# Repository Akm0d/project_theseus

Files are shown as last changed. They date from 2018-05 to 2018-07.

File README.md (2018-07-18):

# Project Theseus
This project is forked from the private repo of the OpenWest Defusal Station project. It is named "Project Theseus" after the paradox of the Ship of Theseus; a thought experiment that raises the question of whether an object that has had all of its components replaced remains fundamentally the same object.

# Contribution Guidelines
1. Create a branch for your code and merge it to master once the changes are stable
2. Keep the file structure as organized as possible
3. Never commit binaries, hidden files created by your IDE, or Windows-style line endings.
4. Keep detailed comments of what each function is meant to do
5. Follow the PEP-8 standard when writing python https://www.python.org/dev/peps/pep-0008/
6. Use comments starting with TODO to mark a feature that needs to be implemented and FIXME to mark features that need to be improved
7. If you are stuck, then it is absolutely OK to ask for help

# Getting Started
```bash
$ sudo apt-get update
$ sudo apt-get install python3 git python3-pip
$ git clone https://github.com/jtylers/project_theseus.git
$ cd project_theseus
$ git submodule update --init
$ pip3 install -r requirements.txt
$ ./serve.py
$ firefox 127.0.0.1:5000
```
I highly suggest using PyCharm if you are working with Flask and Python
```bash
$ sudo apt-get update
$ sudo apt-get install snapd
$ snap install pycharm-community
```
Add the project root to your python path for things to run correctly
```bash
$ echo "export PYTHONPATH=$PYTHONPATH:$HOME/project_theseus" >> ~/.profile
$ source ~/.profile
```

## Raspberry pi - ARCH Linux Setup
```bash
$ ## login with user: root password: root
$ # Delete default user
$ userdel alarm
$ # Create a new adminuser
$ useradd admin
$ # Set password for admin
$ passwd admin
$ # Make a home folder for admin
$ mkdir -p /home/admin
$ # Change ownership of the admin's home folder
$ chown -R admin:admin /home/admin
$ pacman -S sudo
$ # Grant admin sudo privileges
$ visudo
$ ## Press SHIFT + G then SHIFT + A
$ ## type "admin ALL=(ALL) ALL" without the quotes
$ ## save and quit by pressing ESCAPE, typing ":x" and pressing ENTER
$ # Remove root's password entry so that you can only log in as "admin" and use sudo and to do root stuff
$ vim /etc/shadow
$ ## replace root's password hash with !
$ # Install dependencies
$ pacman -S fakeroot gcc git i2c-tools make nginx packer python python-dateutil python-flask python-flask-restful python-pip tmux vim 
$ packer -S raspi-config
$ # Enable I2C 
$ echo "dtparam=i2c_arm=on"| sudo tee -a /boot/config.txt
$ sudo reboot
$ ## Log in as admin
$ ## Allow admin to access i2c
$ sudo chown admin:admin /dev/i2c*
$ ## Proceed with the instructions from the "Getting Started" section
$ ## Run project_theseus/pi_setup.sh
```

## Where are variables stored?
Stored in the database
```
ID
Name
Laser   -- Deprecated
Code
Color
Time    -- Stored as a datetime object but written at end of game
Success
```

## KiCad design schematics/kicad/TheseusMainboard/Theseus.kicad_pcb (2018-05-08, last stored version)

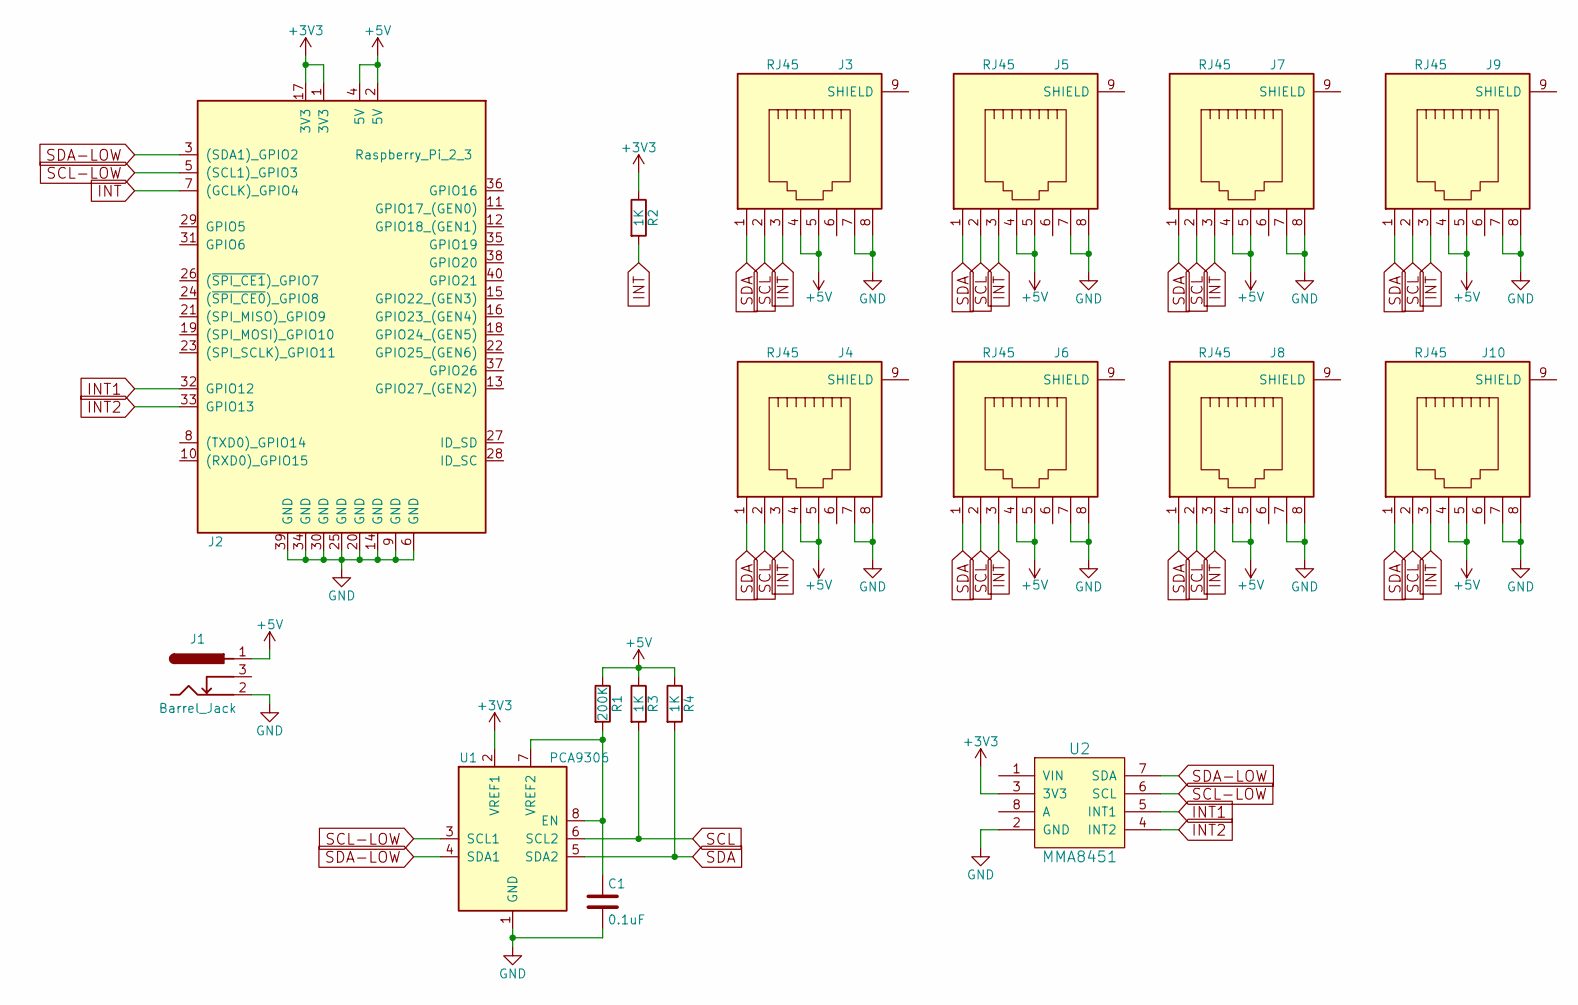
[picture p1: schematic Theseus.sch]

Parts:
C1: 0.1uF; C_0805_HandSoldering
J1: Barrel_Jack; POWER_JACK_PTH
J2: Raspberry_Pi_2_3; Pin_Header_Straight_2x20
J3, J4, J5, J6, J7, J8, J9, J10: RJ45; RJ45-8
R1: 200K; R_0805_HandSoldering
R2, R3, R4: 1K; R_0805_HandSoldering
U1: PCA9306; SO08
U2: MMA8451; Pin_Header_Straight_1x08_Pitch2.54mm

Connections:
+3V3: J2.1 (3V3), J2.17 (3V3), R2.1, U1.2 (VREF1), U2.3 (3V3)
+5V: J1.1, J2.2 (5V), J2.4 (5V), J3.4, J3.5, J4.4, J4.5, J5.4, J5.5, J6.4, J6.5, J7.4, J7.5, J8.4, J8.5, J9.4, J9.5, J10.4, J10.5, R1.1, R3.1, R4.1
GND: C1.2, J1.2, J2.6 (GND), J2.9 (GND), J2.14 (GND), J2.20 (GND), J2.25 (GND), J2.30 (GND), J2.34 (GND), J2.39 (GND), J3.7, J3.8, J4.7, J4.8, J5.7, J5.8, J6.7, J6.8, J7.7, J7.8, J8.7, J8.8, J9.7, J9.8, J10.7, J10.8, U1.1 (GND), U2.2 (GND)
INT: J2.7 ((GCLK)_GPIO4), J3.3, J4.3, J5.3, J6.3, J7.3, J8.3, J9.3, J10.3, R2.2
INT1: J2.32 (GPIO12), U2.5 (INT1)
INT2: J2.33 (GPIO13), U2.4 (INT2)
unnamed: C1.1, R1.2, U1.7 (VREF2), U1.8 (EN)
SCL: J3.2, J4.2, J5.2, J6.2, J7.2, J8.2, J9.2, J10.2, R3.2, U1.6 (SCL2)
SCL-LOW: J2.5 ((SCL1)_GPIO3), U1.3 (SCL1), U2.6 (SCL)
SDA: J3.1, J4.1, J5.1, J6.1, J7.1, J8.1, J9.1, J10.1, R4.2, U1.5 (SDA2)
SDA-LOW: J2.3 ((SDA1)_GPIO2), U1.4 (SDA1), U2.7 (SDA)

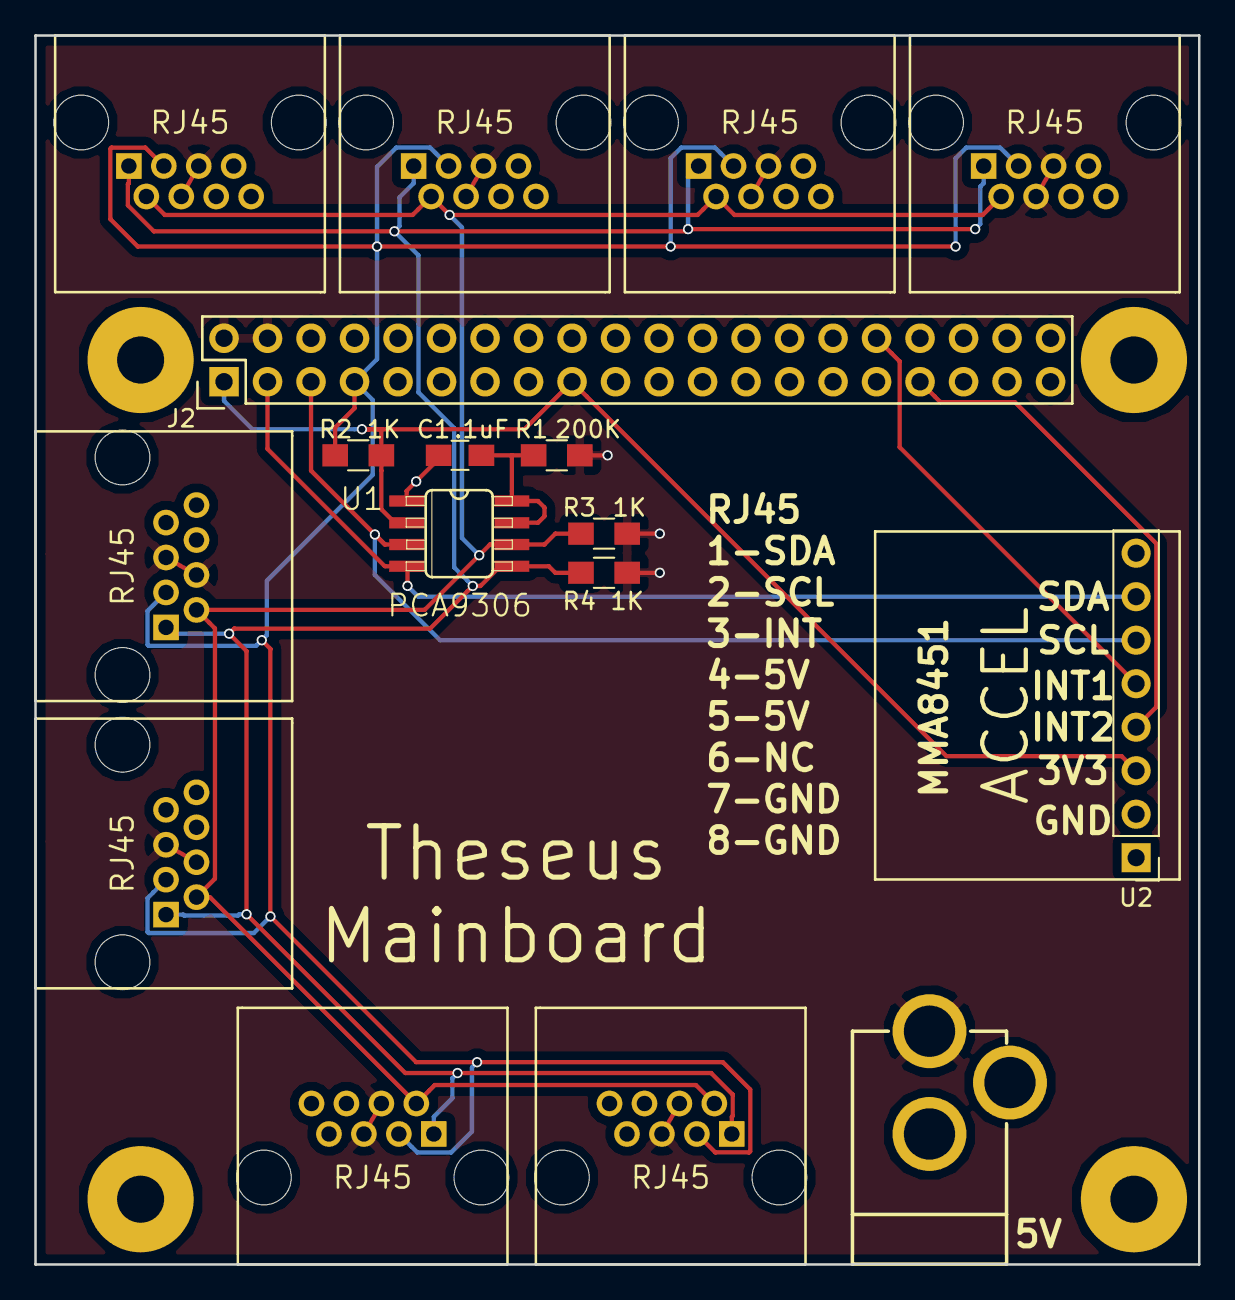
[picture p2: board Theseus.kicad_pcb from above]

Board: 2 copper layers, 67.9 x 71.8 mm, 17 parts (0 on the bottom side), 11 nets.

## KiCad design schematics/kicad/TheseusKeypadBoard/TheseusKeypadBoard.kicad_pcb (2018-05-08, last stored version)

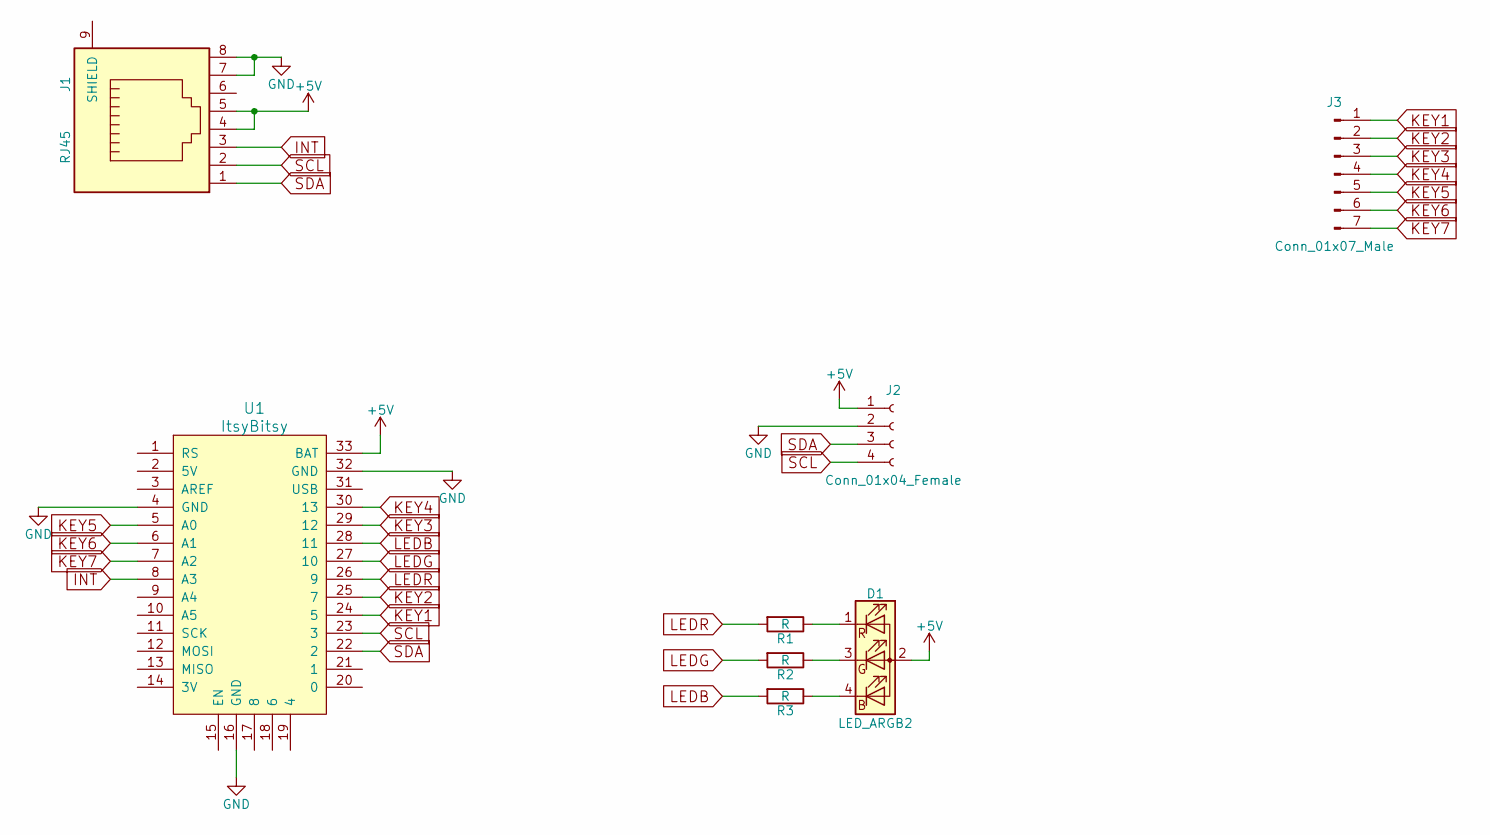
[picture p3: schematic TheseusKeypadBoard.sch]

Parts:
D1: LED_ARGB2
J1: RJ45; RJ45-8
J2: Conn_01x04_Female; Pin_Header_Straight_1x04_Pitch2.54mm
J3: Conn_01x07_Male; Pin_Header_Straight_1x07_Pitch2.54mm
R1, R2, R3: R; R_0805_HandSoldering
U1: ItsyBitsy

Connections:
+5V: D1.2 (A), J1.4, J1.5, J2.1, U1.33 (BAT)
GND: J1.7, J1.8, J2.2, U1.4 (GND), U1.16 (GND), U1.32 (GND)
INT: J1.3, U1.8 (A3)
KEY1: J3.1, U1.24 (5)
KEY2: J3.2, U1.25 (7)
KEY3: J3.3, U1.29 (12)
KEY4: J3.4, U1.30 (13)
KEY5: J3.5, U1.5 (A0)
KEY6: J3.6, U1.6 (A1)
KEY7: J3.7, U1.7 (A2)
LEDB: R3.2, U1.28 (11)
LEDG: R2.2, U1.27 (10)
LEDR: R1.2, U1.26 (9)
unnamed: D1.1 (RK), R1.1
unnamed: D1.3 (GK), R2.1
unnamed: D1.4 (BK), R3.1
SCL: J1.2, J2.4, U1.23 (3)
SDA: J1.1, J2.3, U1.22 (2)

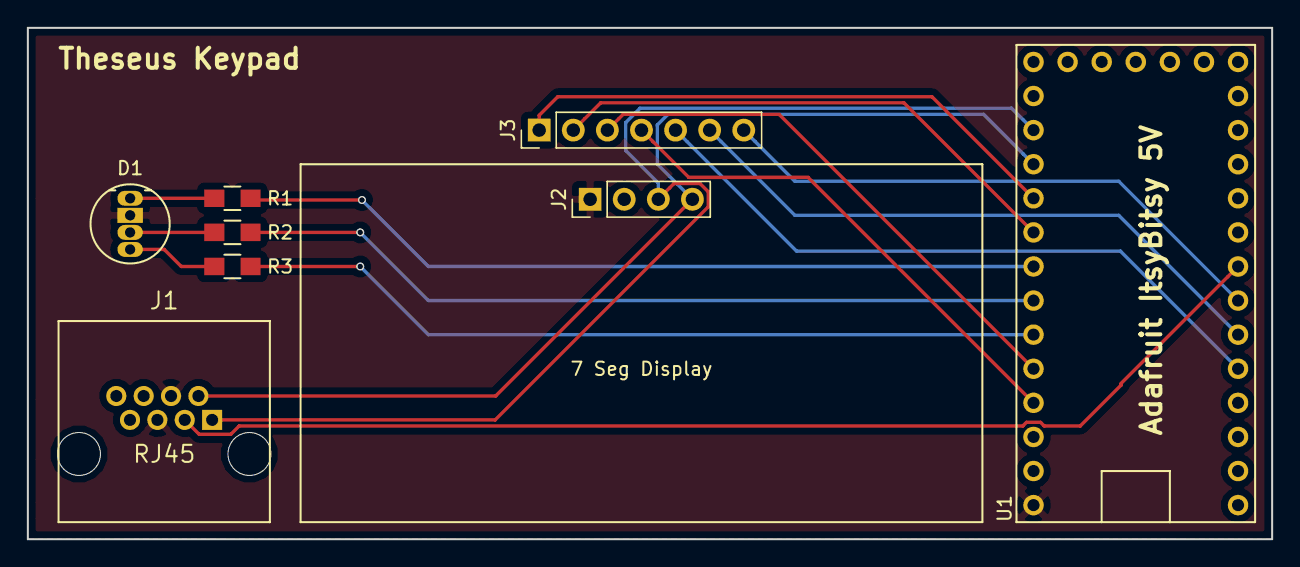
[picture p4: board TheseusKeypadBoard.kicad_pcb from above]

Board: 2 copper layers, 92.7 x 38.1 mm, 8 parts (0 on the bottom side), 18 nets.

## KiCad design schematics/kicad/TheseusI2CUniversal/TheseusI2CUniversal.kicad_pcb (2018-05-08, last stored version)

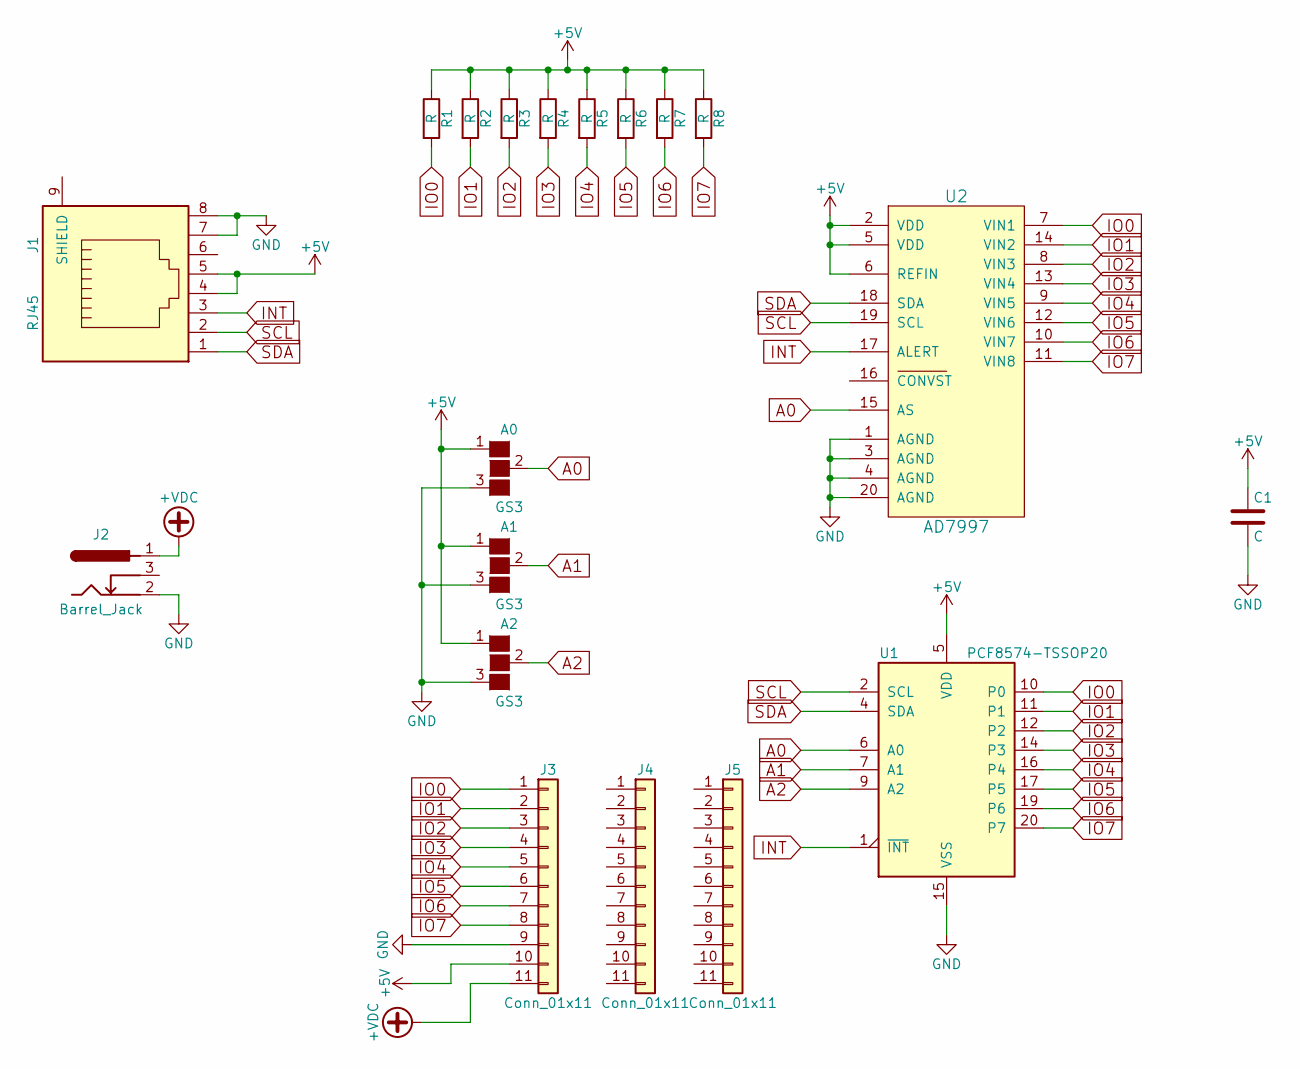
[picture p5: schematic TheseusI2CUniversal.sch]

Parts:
A0, A1, A2: GS3
C1: C; C_0805_HandSoldering
J1: RJ45; RJ45-8
J2: Barrel_Jack; POWER_JACK_PTH
J3, J4, J5: Conn_01x11; Socket_Strip_Straight_1x11_Pitch2.54mm
R1, R2, R3, R4, R5, R6, R7, R8: R; R_0805_HandSoldering
U1: PCF8574-TSSOP20; TSSOP20
U2: AD7997; TSSOP20

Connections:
+5V: A0.1 (G1), A1.1 (G1), A2.1 (G1), C1.1, J1.4, J1.5, J3.10, R1.1, R2.1, R3.1, R4.1, R5.1, R6.1, R7.1, R8.1, U1.5 (VDD), U2.2 (VDD), U2.5 (VDD), U2.6 (REFIN)
+VDC: J2.1, J3.11
A0: A0.2 (G2), U1.6 (A0), U2.15 (AS)
A1: A1.2 (G2), U1.7 (A1)
A2: A2.2 (G2), U1.9 (A2)
GND: A0.3 (G3), A1.3 (G3), A2.3 (G3), C1.2, J1.7, J1.8, J2.2, J3.9, U1.15 (VSS), U2.1 (AGND), U2.3 (AGND), U2.4 (AGND), U2.20 (AGND)
INT: J1.3, U1.1 (~INT~), U2.17 (ALERT)
IO0: J3.1, R1.2, U1.10 (P0), U2.7 (VIN1)
IO1: J3.2, R2.2, U1.11 (P1), U2.14 (VIN2)
IO2: J3.3, R3.2, U1.12 (P2), U2.8 (VIN3)
IO3: J3.4, R4.2, U1.14 (P3), U2.13 (VIN4)
IO4: J3.5, R5.2, U1.16 (P4), U2.9 (VIN5)
IO5: J3.6, R6.2, U1.17 (P5), U2.12 (VIN6)
IO6: J3.7, R7.2, U1.19 (P6), U2.10 (VIN7)
IO7: J3.8, R8.2, U1.20 (P7), U2.11 (VIN8)
SCL: J1.2, U1.2 (SCL), U2.19 (SCL)
SDA: J1.1, U1.4 (SDA), U2.18 (SDA)

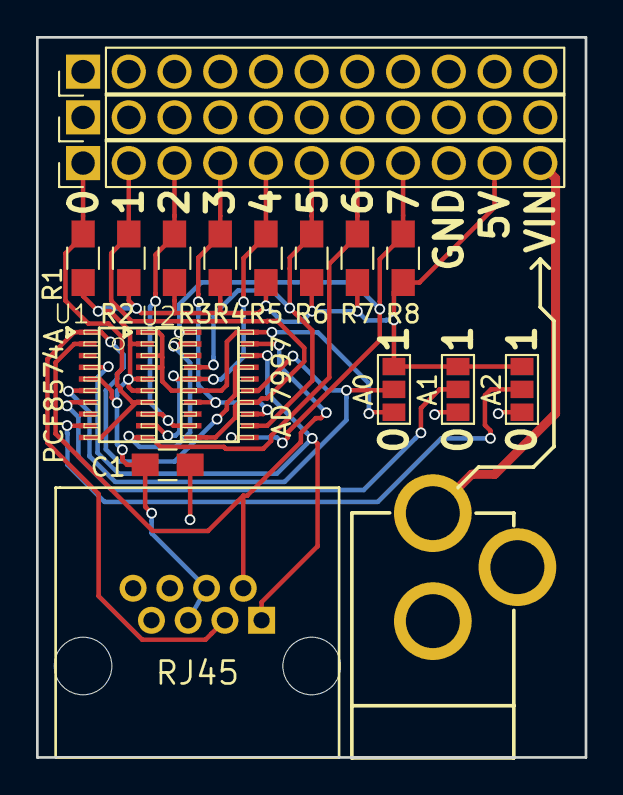
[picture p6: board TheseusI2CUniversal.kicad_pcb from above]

Board: 2 copper layers, 30.5 x 40.0 mm, 19 parts (0 on the bottom side), 17 nets.

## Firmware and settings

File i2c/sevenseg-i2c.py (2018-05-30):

from time import sleep

import smbus


class SevenSegDisplay:
    ADDR = 0x70
    BLINK_CMD = 0x80
    BLINK_DISPLAY_ON = 0x01
    CMD_BRIGHTNESS = 0xE0
    COLON = 0x02
    CHARMAP = {
        '0': 0x3F,
        '1': 0x06,
        '2': 0x5B,
        '3': 0x4F,
        '4': 0x66,
        '5': 0x6D,
        '6': 0x7D,
        '7': 0x07,
        '8': 0x7F,
        '9': 0x6F,
        'a': 0x77,
        'b': 0x7C,
        'c': 0x39,
        'd': 0x5E,
        'e': 0x79,
        'f': 0x71}

    def __init__(self, bus):
        self.bus = bus
        self.chars = bytearray(4)
        self.dots = [False] * 4
        self.colon = False
        self.buf = [0] * 5

    def set_digits(self, digits):
        if len(digits) != 4:
            return
        for i, c in enumerate(digits):
            self.chars[i] = self.CHARMAP[c]

    def update(self):
        self.buf = []
        for i in range(4):
            self.buf.append((self.dots[i] << 7) | self.chars[i])
            self.buf.append(0)
            if i == 1:
                self.buf.append(self.COLON if self.colon else 0)
                self.buf.append(0)
        self.buf.extend([0] * 6)
        # print(self.buf)
        self.bus.write_i2c_block_data(self.ADDR, 0, self.buf)

    def begin(self):
        self.write_byte(0x21)  # start oscillator
        self.blink_rate(0)
        self.set_brightness(15)

    def write_byte(self, byte: hex):
        self.bus.write_byte(self.ADDR, byte)

    def set_brightness(self, level):
        level = 0 if level > 15 else level
        self.write_byte(self.CMD_BRIGHTNESS | level)

    def blink_rate(self, rate=0):
        rate = rate if rate <= 3 else 0
        self.write_byte(self.BLINK_CMD | self.BLINK_DISPLAY_ON | (rate << 1))


def main(argv):
    bus = smbus.SMBus(1)
    sevenseg = SevenSegDisplay(bus)
    sevenseg.begin()
    # sevenseg.blink_rate(1)
    # sevenseg.dots = [True]*4
    # sevenseg.colon = True
    for n in range(1000):
        s = str(n).rjust(4, '0')
        # s = '2980'
        sevenseg.set_digits(s)
        sevenseg.update()
        sleep(.01)

    sevenseg.set_digits('beef')
    sevenseg.update()


if __name__ == '__main__':
    import sys

    main(sys.argv)

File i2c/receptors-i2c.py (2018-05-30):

from array import array
from enum import IntEnum
from struct import unpack
from time import sleep

from smbus import SMBus

from i2c.i2c_module import I2CModule


class ReceptorRegisters(IntEnum):
    Conversion = 0x00,
    Alert = 0x01,
    Config = 0x02,
    CycleTime = 0x03,
    Data1Low = 0x04,
    Data1High = 0x05,
    Hyst1 = 0x06,
    Data2Low = 0x07,
    Data2High = 0x08,
    Hyst2 = 0x09,
    Data3Low = 0x0A,
    Data3High = 0x0B,
    Hyst3 = 0x0C,
    Data4Low = 0x0D,
    Data4High = 0x0E,
    Hyst4 = 0x0F


class ReceptorControl(I2CModule):
    RECEPTOR_COUNT = 6
    CHANNEL = [0x80, 0x90, 0xA0, 0xB0, 0xC0, 0xD0, 0xE0, 0xF0]
    CONFIG = [0x03, 0xF8]
    READ_ALL = 0x70
    # UNPACK_ALL = ''.join(['>'].extend(['H']*RECEPTOR_COUNT))
    UNPACK_ALL = '>HHHHHH'

    def __init__(self, bus: SMBus, address: hex = 0x21):
        super().__init__(bus, address)
        self.receptors = [0] * self.RECEPTOR_COUNT
        self.write_reg_bytes(ReceptorRegisters.Config, self.CONFIG)

    def read_all(self):
        _, data = self.read_reg_bytes(self.READ_ALL, 2 * self.RECEPTOR_COUNT)
        self.receptors = list(unpack(self.UNPACK_ALL, array('B', data).tostring()))
        return self.receptors

    def read(self, n):
        sleep(.5)
        if n >= self.RECEPTOR_COUNT:
            return None
        _, data = self.read_reg_bytes(self.CHANNEL[n], 2)
        data2 = unpack('>H', array('B', data).tostring())
        self.receptors[n] = data2[0]
        return self.receptors[n]


if __name__ == '__main__':
    master = SMBus(1)
    read = ReceptorControl(master)
    while True:
        # print('{}, {}, {}, {}, {}, {}'.format(*[read.read(n) for n in range(6)]))
        # print(read.read_all())
        print(read.read(1))
        sleep(1)

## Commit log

2018-01-24 Forked from Defusal Station v1
    [7seg_keypad.sch, box_board.sch, leds.sch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]
2018-02-18 Added basic admin page that has a few buttons
2018-02-19 Added color wheel selection to api
2018-02-21 if keycode is blank then return the current keycode
2018-02-22 Added I2C requirements
2018-02-27 Removed mock libraries until i2c is figured out
2018-03-02 Mock libraries work correctly
    [logic.py]
2018-03-03 The RPi2 uses i2c-1
2018-03-05 Write i2c block data instead of a single byte
2018-05-05 Running the program in a single thread, use pubsub for events
2018-05-05 de pluralize state
2018-05-05 Adds /successes/ /attempts/ /high-scores/ /timer-text/
    successes provides a number of successes
    attempts provides a number of attempts
    high-scores will return a JSON of the top 5 teams
    timer-text returns timer text formatted like '00:00'
2018-05-06 Updates highscores url to provide time information.
    * Updates Resources.py to return dictionary of dictionaries about each entry
    * Updates index.html to have necessary id's for table data entries
    * Updates index.js to also update the timer code.
2018-05-06 admin.html and admin.js
    - Applied CSS and bootstrap changin the admin.js where necessary to get certain stylistic things to work
    - IMPORTANT TO NOTE that Tripwires is not functioning as it should, but hey, it's late and I want to go to bed.
2018-05-06 Fix for admin.js
    - So it turns out that the mind doesn't let you go to bed unless you've solved that problem...and I did
2018-05-06 Adds code necessary to simulate timer running while using --mock
    Adds timer variable to Logic
    Adds timer reduction in _run
    Adds mock variable in Logic to track if we are on the py
2018-05-06 Remove duplicate timer functions, unified team name input to work the same as everything else on admin page
2018-05-07 Added success and boom to timer
2018-05-07 Finalizes multiprocess communication.
    * Creates Enum for the communication strings
    * Changes all instances of message sending to proper Enum
    * Creates constant INTERRUPTS_PER_SECOND for how many times _loop should run per second
    * Creates SLEEP_INTERVAL based on INTERRUPTS_PER_SECOND that tells Logic.run() how long to sleep between running _loop
    * Adds communication handling inside _loop
    * Adds code to run timer
    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
2018-05-07 Updates index.js to make timer update every second, and everything else less often.
    The reasoning behind this is simple. It results in a much smoother timer, and we don't care about the high scores, attempts, and successes every second. It is doubtful these will change every second.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
2018-05-07 Updates to allow controlling solenoid from admin console.
2018-05-07 Removed outdated/un-needed files added new schematics
    [7seg_keypad.sch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]
2018-05-09 Updates Timer to uses JSCom
2018-05-09 Database prep
    Have more than 10 values in the database ready to implement filtering
2018-05-09 Changes timer to use datetime object
2018-05-09 Connects ultrasonic to Logic()
2018-05-09 Configured logger correctly in all files - Fixed some Pep-008 formatting errors
    [logic.py]
2018-05-09 RGB and Keycode work correctly
    [logic.py]
2018-05-10 switched from radio buttons to checkboxes
2018-05-10 Added lasers to gui
2018-05-10 Added frames and removed some checkability
2018-05-10 Added example of function connecting to button
2018-05-15 Cleaned up i2c library
2018-05-16 Timer works again
2018-05-16 Cleaned up old code and fixed scoring
    [logic.py]
2018-05-16 Modifying last row works correctly
    [logic.py]
2018-05-17 Fixed laser binary
2018-05-17 Fixed start button value in all states
2018-05-18 Connected rotary encoder
2018-05-18 Connected Switches
2018-05-18 Added start reset button to mock box
2018-05-18 Programmed mock reset button
2018-05-19 Reorganized GUI. prints are logs
2018-05-21 Added ultrasonic sensor to gui
2018-05-21 Connected ultrasonic sensor to Mock I2C
2018-05-22 created arduino code folder again
2018-05-30 added i2c class
2018-05-30 Adds laser pattern code
2018-05-30 Sets up laser updating
2018-05-30 Moved arduino code to correct folder
2018-05-30 Fixes errors with i2c and my code
    [logic.py]
2018-05-30 Fixes error in property code
    [logic.py]
2018-05-30 Fixes errors with old lasers object
    [logic.py]
2018-05-30 Fixed intenum typecasting errors
    [receptors-i2c.py]
2018-05-30 Fixes errors with lasers
    [logic.py]
2018-05-30 Added Mock libraries and todo for i2c lib
2018-05-31 updates to randomize and run lasers when game is done
2018-05-31 Fixes random button
2018-05-31 I2c modules use constants
2018-05-31 Fixes lasers file
2018-05-31 Arduino code is up to date
2018-06-03 Sevengseg and lid kit are TWO SEPRATE I2C adresses
2018-06-03 Able to read and write from arduino I2c
2018-06-05 Fixed some i2c stuff, oh yeah, and we are using ipv6 too
2018-06-06 Adds laser code: TODO: Fix sevenseg.py
2018-06-06 Added i2c constants
2018-06-06 Added switch code, testing is a little more robust too, good stuff, makes my mamma proud :)
2018-06-06 Fixed up some of the switches everything is typed nicely
    [logic.py]
2018-06-07 Working keypad, revamped lasers, potentially working lock
2018-06-07 Fixed laser and lidkit modules
2018-06-08 Adds read_int function for easy comparison to lasers
2018-06-08 Fixed color bug in logic.py
    [logic.py]
2018-07-14 Moves API code to API folder
    [Theseus-B.Cu.gbl, Theseus-B.Mask.gbs, Theseus-B.SilkS.gbo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]
2018-07-19 Don't try and read sensors if they are disconnected
2018-08-04 Updates to get laser updates in API
2018-08-04 Added code that kills player if time runs out or lasers are blocked
2018-09-12 Adds new ways to die!
    The switches now correspond with how the RGB LED lights up to indicate the proper keypad code.
    Typing in the wrong code kills the player.
    Blocking a laser will kill the player.
    TODO: The updateLed function makes some assumptions as to how the switches return. A verification needs to take place as this may not work as Graigry thought.
    [logic.py]
2018-09-13 Debugs problem with code.
    The issue is that many of the commands sent by the Webserver are still sent via the old shared queue method. However, as far as I can tell, the logic isn't access it. All of these funtions need to be changed to use the shared dictionary instead. I started work on changing the start button to use the dictionary, but there are still some bugs to work out.
    [logic.py]
